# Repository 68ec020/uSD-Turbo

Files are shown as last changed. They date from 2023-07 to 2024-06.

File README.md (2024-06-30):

# BBC Micro TurboMMC Interface

Use with
https://github.com/hoglet67/MMFS

Inspired by
http://stardot.org.uk/forums/viewtopic.php?t=9445&f=3#p110691

The interface works in my BBC Micro. I included resisters everywhere two outputs could be active at the same time, like in the hand-drawn schematic. So it should be safe. But: Use at your own risk!

## Changes compared to the hand-drawn schematic

* active level shifters (74LVC125AD) instead of voltage dividers
* 3.3 V voltage regulator
* no pull-ups on PB2, PB3, PB4, marked with VDD ? in the hand-drawn schematic (maybe I should add them, if the port is configured as input)

## Build your own

I ordered PCBs from JLCPCB. Just use the file jlcpcb/production_files/GERBER-uSD-Turbo.zip

Use the HTML-based BOM tool in /bom

I bought a microSD card slot on eBay, but I don't have a specific part number.

Make sure the right angle connector is mounted like in the 2D rendering. Pin 1 is the sqare pad. Make sure this corresponds with pin 1 of your port!

uSD-Turbo

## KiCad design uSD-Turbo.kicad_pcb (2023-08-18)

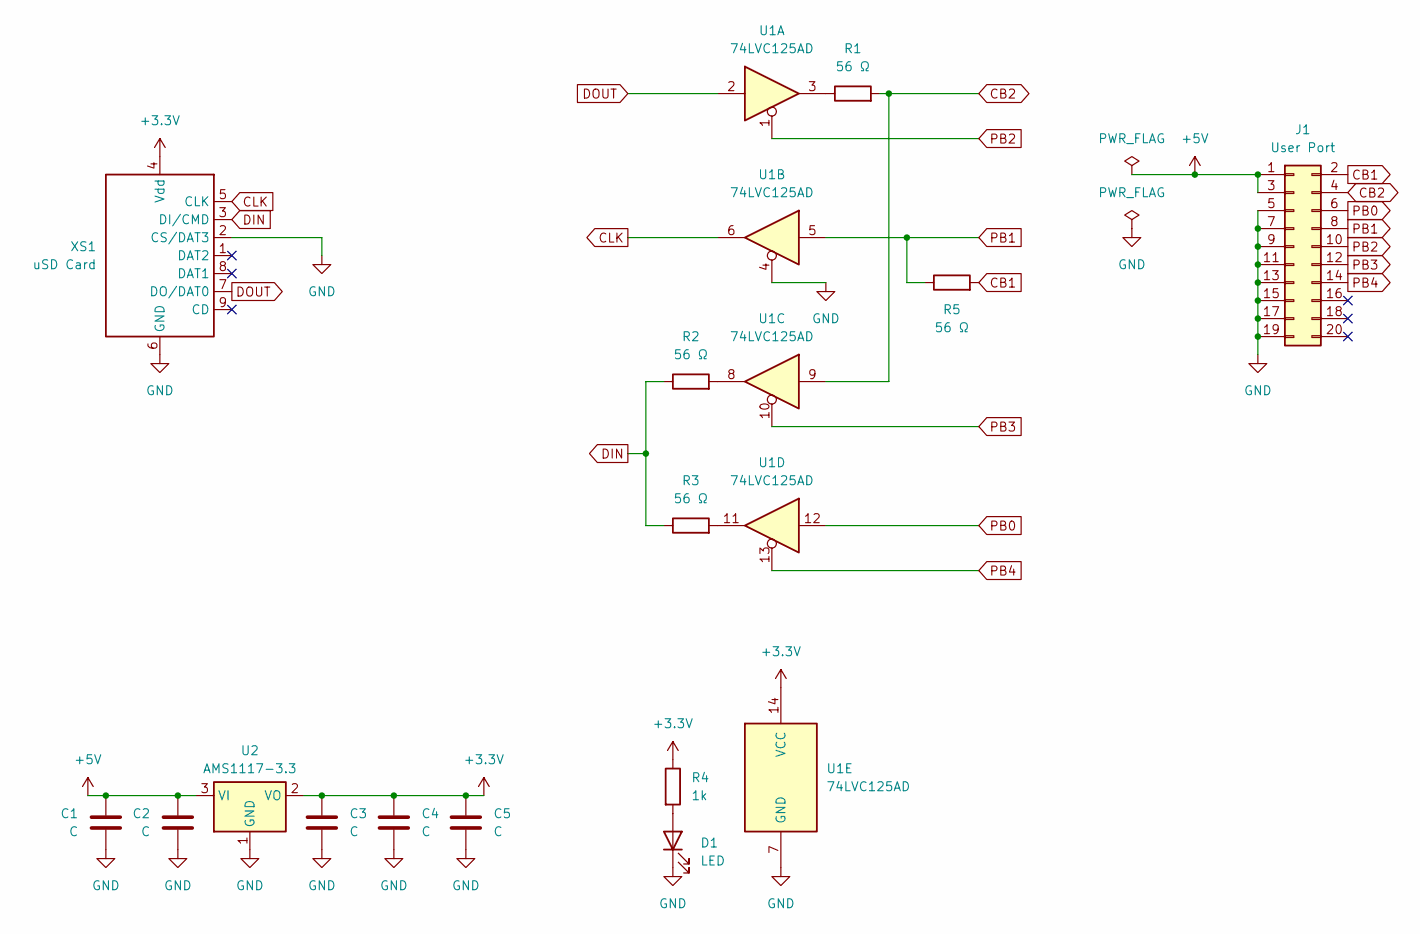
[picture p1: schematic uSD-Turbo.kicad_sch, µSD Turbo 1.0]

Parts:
C1, C2, C3, C4, C5: C; C_0603_1608Metric
D1: LED; LED_0603_1608Metric
J1: User Port; PinSocket_2x10_P2.54mm_Horizontal
R1, R2, R3, R5: 56 Ω; R_0603_1608Metric
R4: 1k; R_0603_1608Metric
U1: 74LVC125AD; SOIC-14_3.9x8.7mm_P1.27mm
U2: AMS1117-3.3; SOT-223-3_TabPin2
XS1: uSD Card; Conn_uSDcard

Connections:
+3.3V: C3.1, C4.1, C5.1, R4.1, U1.14 (VCC), U2.2 (VO), XS1.4 (Vdd)
+5V: C1.1, C2.1, J1.1, J1.3, U2.3 (VI)
CB1: J1.2, R5.2
CB2: J1.4, R1.2, U1.9
CLK: U1.6, XS1.5 (CLK)
DIN: R2.1, R3.1, XS1.3 (DI/CMD)
DOUT: U1.2, XS1.7 (DO/DAT0)
GND: C1.2, C2.2, C3.2, C4.2, C5.2, D1.1 (K), J1.5, J1.7, J1.9, J1.11, J1.13, J1.15, J1.17, J1.19, U1.4, U1.7 (GND), U2.1 (GND), XS1.2 (CS/DAT3), XS1.6 (GND)
unnamed: D1.2 (A), R4.2
unnamed: R1.1, U1.3
unnamed: R2.2, U1.8
unnamed: R3.2, U1.11
PB0: J1.6, U1.12
PB1: J1.8, R5.1, U1.5
PB2: J1.10, U1.1
PB3: J1.12, U1.10
PB4: J1.14, U1.13

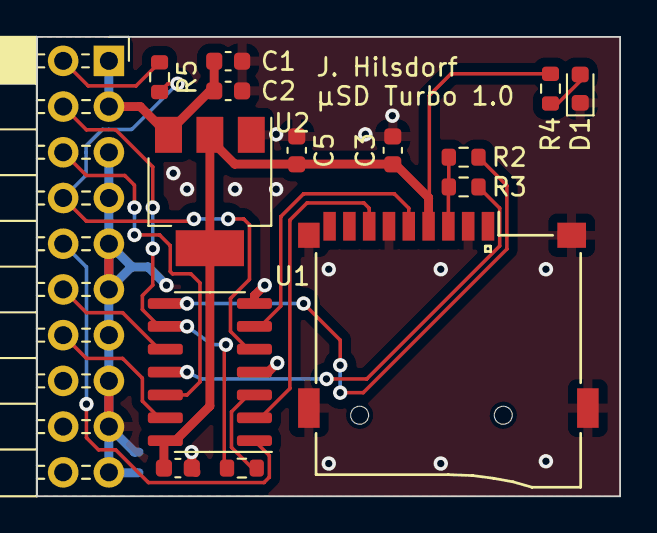
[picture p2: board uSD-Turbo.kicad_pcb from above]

Board: 2 copper layers, 32.4 x 25.5 mm, 15 parts (0 on the bottom side), 17 nets.
